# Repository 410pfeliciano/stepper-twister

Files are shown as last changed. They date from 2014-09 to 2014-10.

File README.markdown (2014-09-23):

=================================
An open-source, very fast tetrode twister for Arduino
=================================

This code requires the [Arduino](http://www.arduino.cc) development environment and an [Arduino board](http://www.sparkfun.com/products/11021>). 

The code has been updated to be compatible with the Arduino IDE version 1.0 and higher. To make it compatible with earlier versions of the IDE, simply include "WProgram.h" instead of "Arduino.h" in the TwisterClasses.h file.

This repository contains circuit board files, a parts list, and an instruction manual.

=================================
Attribution
=================================
This work is basically a direct combination of two existing open-source projects:

1. "Tetrode Twister" by Josh Siegle, which is licensed under [GPLv3](http://www.gnu.org/licenses/gpl-3.0.txt)
    * [Josh on Github](https://github.com/jsiegle)
    * [Twister Project](https://github.com/open-ephys/twister)

2. "Easy Driver" by Brian Schmalz, which is  is licensed under [CC-BY-3.0](https://creativecommons.org/licenses/by/3.0/us/)
    * [Brian's site](http://www.schmalzhaus.com/)
    * [Easy Driver Project](http://www.schmalzhaus.com/EasyDriver/)

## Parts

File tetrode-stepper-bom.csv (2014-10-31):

Sparkfun Part No. | Quantity | Description | Notes
prt-00116 | 2 | Header, 40 pin
com-09939 | 2 | Rotary Pot, 10K
com-10002 | 2 | Knob
LCD-0070 | 1 | LCD Module
DEV-11286 | 1 | Leonardo
TOL-00298 | 1 | Wall wart
COM-07950 | 1 | Buzzer
COM-09190 | 1 | Momentary switch
COM-08605 | 1 | Tall momentary switch
com-09806 | 1 | Trimpot, 10K
ROB-1055 | 1 | Small stepper motor
Digikey | Quantity | Description | Notes
620-1140-1-ND | 1 | Microstepping driver
565-2558-1-ND | 1 | CAP 47UF 35V ELECT MZA SMD
445-1291-1-ND | 2 | Ceramic Cap, 0603, 680pF
445-1419-1-ND | 2 | Ceramic Cap, 0805, 1uF
P10.0KHCT-ND | 8 | Resistor, 0603, 10K
P11.0KHCT-ND | 1 | Resistor, 0603, 11K
P20.0KHCT-ND | 2 | Resistor, 0603, 20K
A109863CT-ND | 2 | Resistor, 1206, 0.75 Ohm
MURS120T3GOSCT-ND | 1 | DIODE ULTRA FAST 200V 2A SMB
McMaster-Carr | Quantity | Description | Notes
94500A222 | 1 | M3 bolt | 100/pack
90592A009 | 1 | M3 Nut | 100/pack
94150a340 | 1 | M5 nut | 25/pack
91292a193 | 1 | M5 bolt | 50/pacl
92871a063 | 4 | M5 Unthreaded spacer, 20mm
92871a040 | 4 | M5 Unthreaded spacer, 5mm
Pololu | Quantity | Description | Notes
1079 | 1 | 3-mm shaft hub | 2/pack
Ponoko | Quantity | Description | Notes
cad/clip-holder.stl | 1 | 3-d printed clip holder | Material = fine, durable plastic, design: http://www.ponoko.com/design-your-own/products/clip-holder-11927
cad/motor-arm.stl | 1 | 3-d printed stepper motor arm | Material = fine, durable plastic, design: http://www.ponoko.com/design-your-own/products/clip-holder-11927

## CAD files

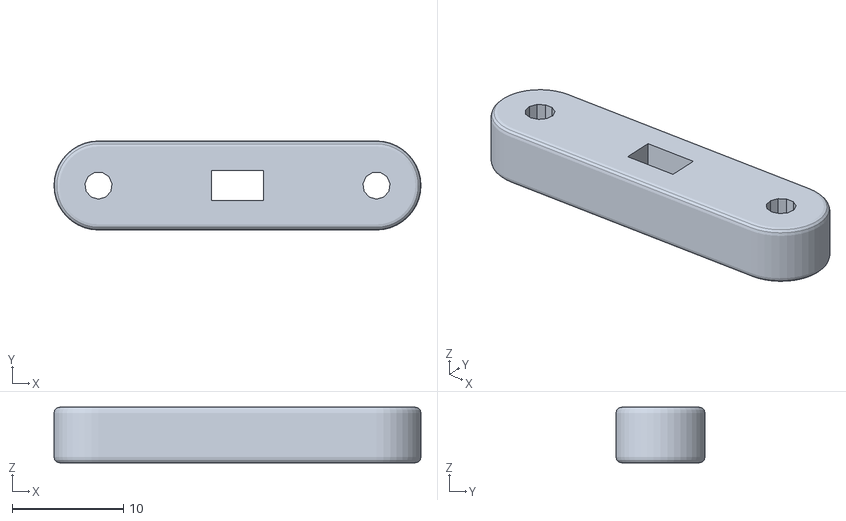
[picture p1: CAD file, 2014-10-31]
cad/clip-holder.stl
33.0 x 8.00 x 5.00

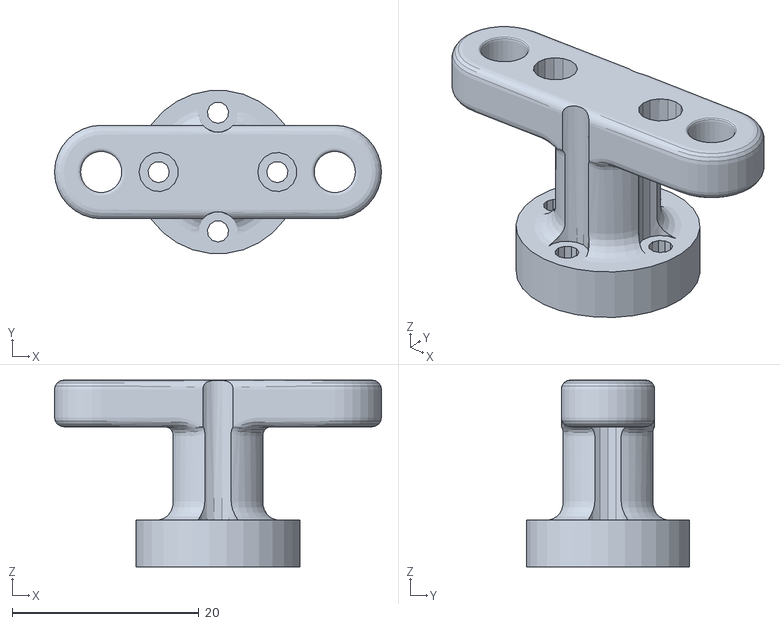
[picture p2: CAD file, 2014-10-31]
cad/motor-arm.stl
35.0 x 17.4 x 20.0

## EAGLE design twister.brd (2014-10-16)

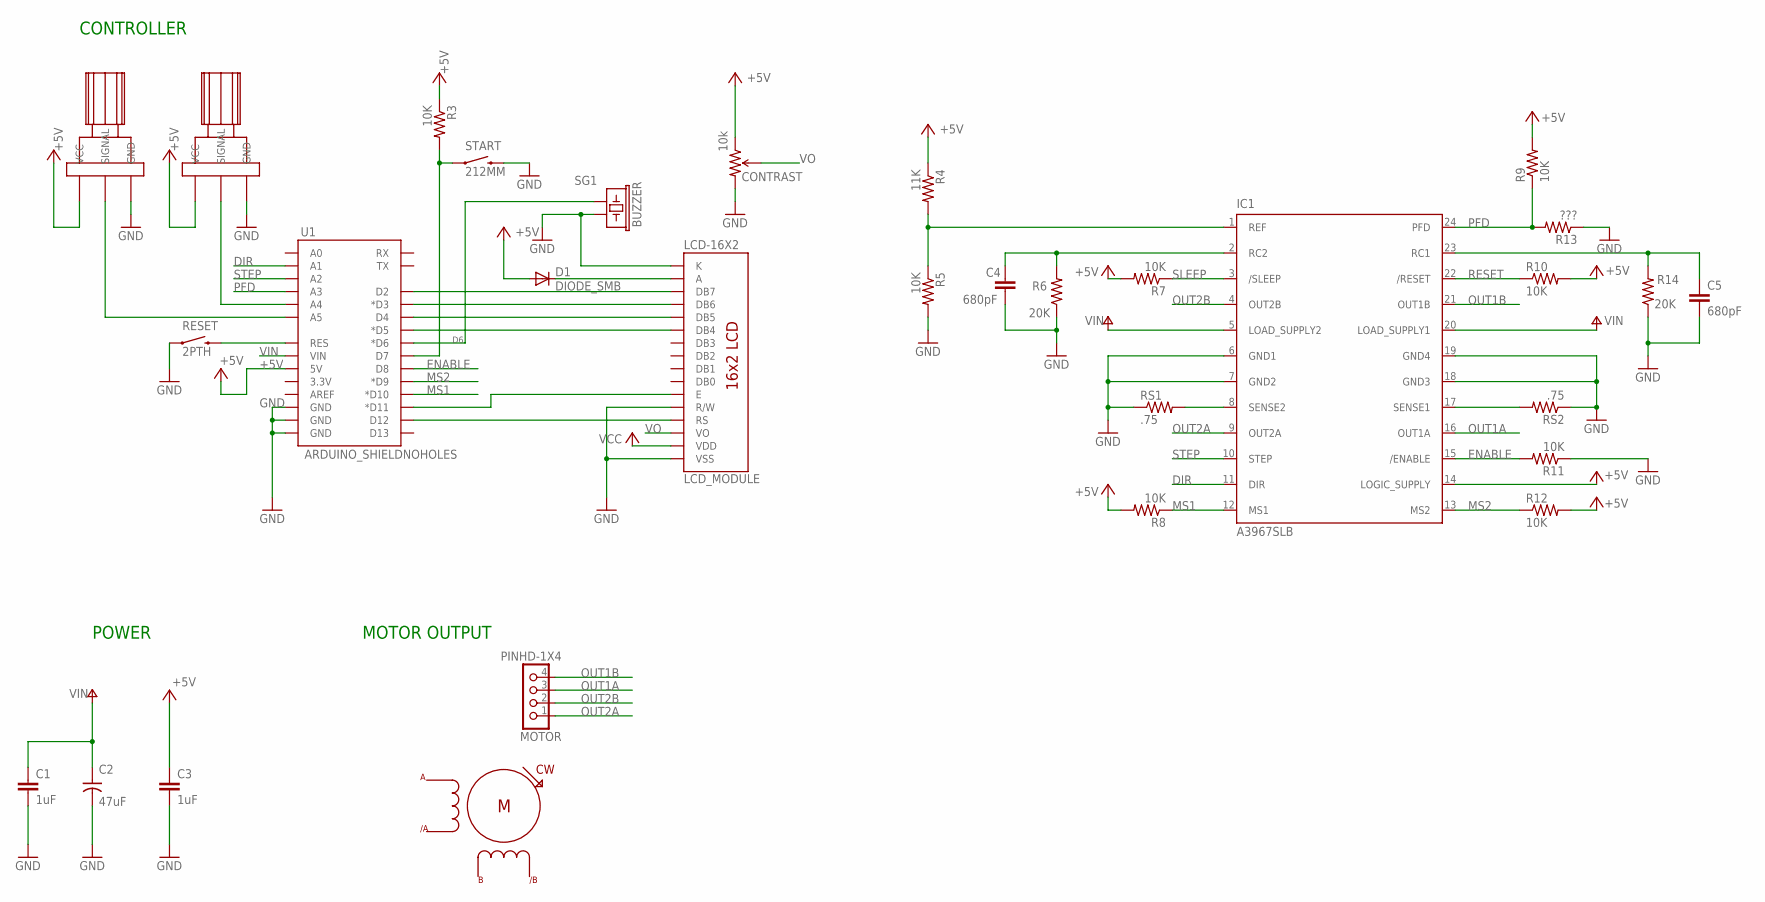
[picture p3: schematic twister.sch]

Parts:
BUZZER: SG1; BUZZER-12MM
C1, C3: 1uF; 0805
C2: 47uF; 153CLV-0807
C4, C5: 680pF; 0603
CONTRAST: 10k; 3362U-2
D1: DIODE_SMB; SMB
IC1: A3967SLB; SO24W
LCD_MODULE: LCD-16X2
MOTOR: PINHD-1X4; 1X04
R1, R2: R12-0; LARGE_POT
R3, R5, R7, R8, R9, R10, R11, R12: 10K; 0603
R4: 11K; 0603
R6, R14: 20K; 0603
R13: ???; 0603
RESET: 2PTH; TACTILE-PTH
RS1, RS2: .75; 1206
START: 212MM; TACTILE-PTH-12MM
STEPPER: ST-PM35; ST-PM35-15-11C
U1: ARDUINO_SHIELDNOHOLES; DUEMILANOVE_SHIELD_NOHOLES

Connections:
+5V: C3.1, CONTRAST.1 (CCW), D1.A, IC1.14 (LOGIC_SUPPLY), LCD_MODULE.2 (VDD), R1.LEFT (VCC), R2.LEFT (VCC), R3.1, R4.1, R7.2, R8.2, R9.2, R10.2, R12.2, U1.5V
A: D1.C, LCD_MODULE.15 (A)
D6: BUZZER.- (2), U1.D6 (*D6)
DIR: IC1.11 (DIR), U1.A1
ENABLE: IC1.15 (/ENABLE), R11.2, U1.D8
GND: BUZZER.+ (1), C1.2, C2.-, C3.2, C4.2, C5.2, CONTRAST.3 (CW), IC1.6 (GND1), IC1.7 (GND2), IC1.18 (GND3), IC1.19 (GND4), LCD_MODULE.1 (VSS), LCD_MODULE.5 (R/W), LCD_MODULE.16 (K), R1.RIGHT (GND), R2.RIGHT (GND), R5.2, R6.1, R11.1, R13.1, R14.1, RESET.1, RS1.1, RS2.1, START.3 (2), U1.GND@0 (GND), U1.GND@1 (GND), U1.GND@2 (GND)
MS1: IC1.12 (MS1), R8.1, U1.D10 (*D10)
MS2: IC1.13 (MS2), R12.1, U1.D9 (*D9)
unnamed: IC1.8 (SENSE2), RS1.2
unnamed: C4.1, IC1.2 (RC2), R6.2
unnamed: IC1.17 (SENSE1), RS2.2
unnamed: LCD_MODULE.4 (RS), U1.D12
unnamed: LCD_MODULE.6 (E), U1.D11 (*D11)
unnamed: LCD_MODULE.11 (DB4), U1.D5 (*D5)
unnamed: LCD_MODULE.12 (DB5), U1.D4
unnamed: LCD_MODULE.13 (DB6), U1.D3 (*D3)
unnamed: LCD_MODULE.14 (DB7), U1.D2
unnamed: R2.CENTER (SIGNAL), U1.A4
unnamed: R1.CENTER (SIGNAL), U1.A5
unnamed: R3.2, START.1, U1.D7
unnamed: C5.1, IC1.23 (RC1), R14.2
unnamed: IC1.1 (REF), R4.2, R5.1
OUT1A: IC1.16 (OUT1A), MOTOR.3
OUT1B: IC1.21 (OUT1B), MOTOR.4
OUT2A: IC1.9 (OUT2A), MOTOR.1
OUT2B: IC1.4 (OUT2B), MOTOR.2
PFD: IC1.24 (PFD), R9.1, R13.2, U1.A3
RESET: IC1.22 (/RESET), R10.1, RESET.3 (2), U1.RES
SLEEP: IC1.3 (/SLEEP), R7.1
STEP: IC1.10 (STEP), U1.A2
VIN: C1.1, C2.+, IC1.5 (LOAD_SUPPLY2), IC1.20 (LOAD_SUPPLY1), U1.VIN
VO: CONTRAST.2 (WIPER), LCD_MODULE.3 (VO)

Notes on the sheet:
POWER
CONTROLLER
MOTOR OUTPUT

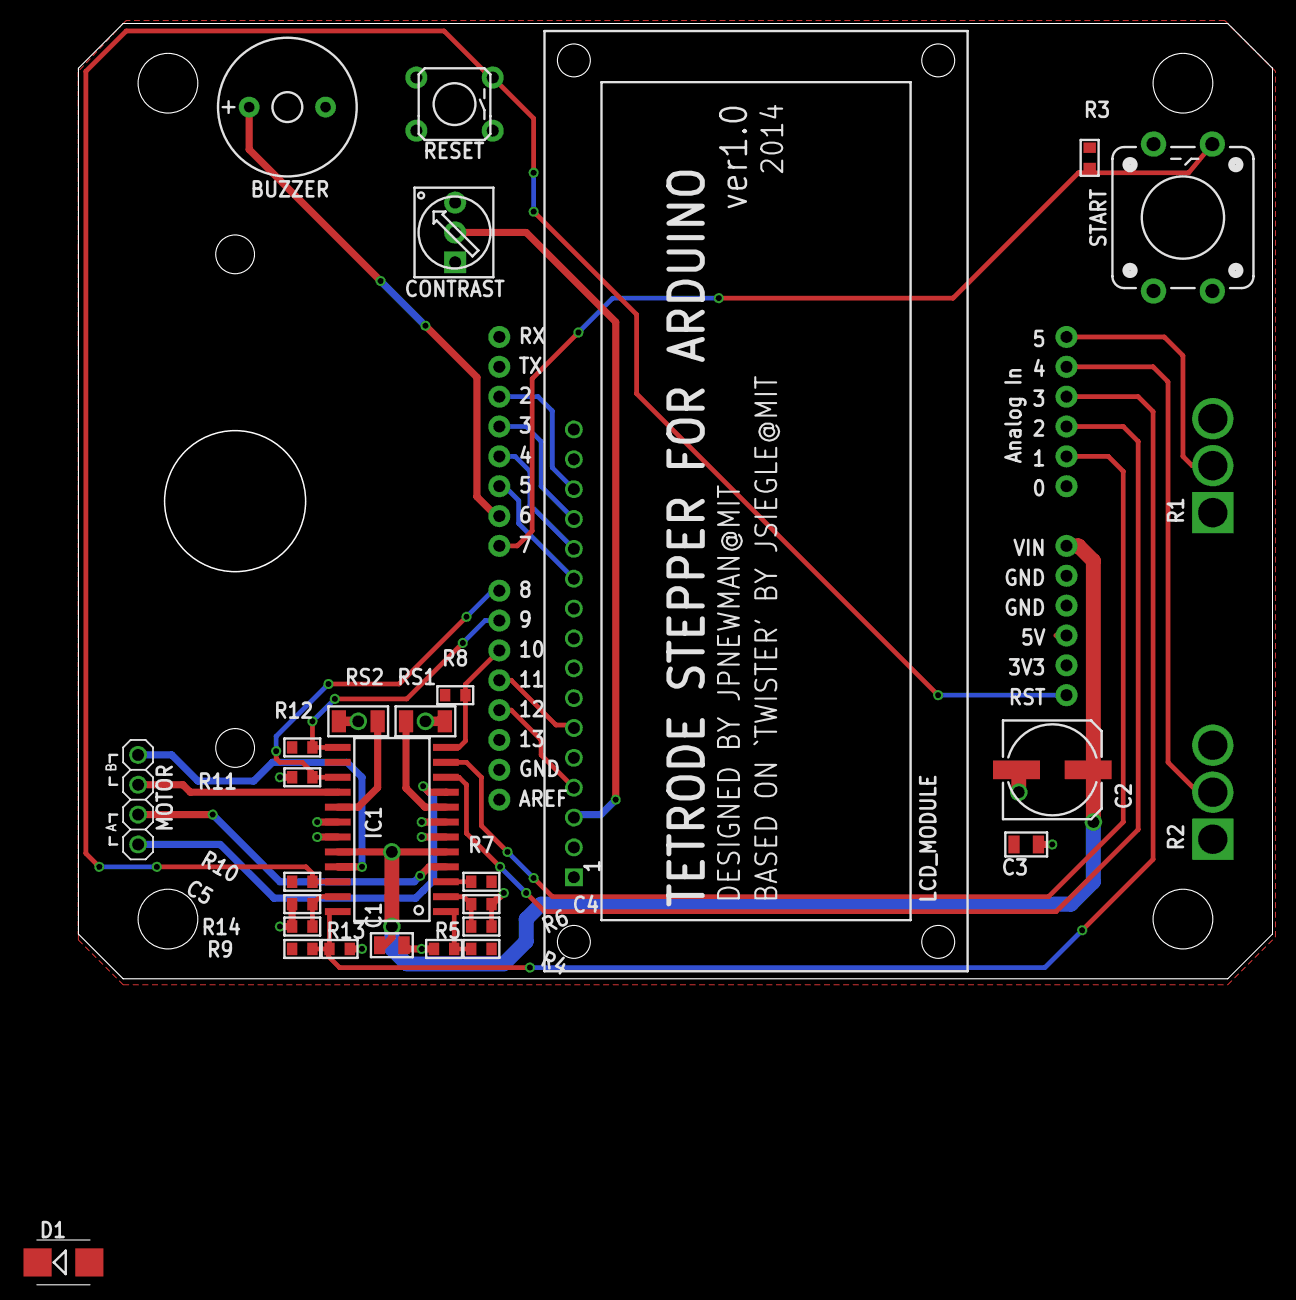
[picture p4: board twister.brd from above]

Board: 2 copper layers, 101.6 x 81.3 mm, 31 parts (1 on the bottom side), 32 nets.

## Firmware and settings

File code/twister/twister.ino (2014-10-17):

//    Tetrode Twister Control Software
//    Copyright (C) 2011 Josh Siegle
//
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

// -------------------------------------------------------------------- //
/*    DEBUG MODE?
 
 If debugMode is set to 'true', photocell values and thresholds
 will be printed to the serial port. These can be visualized 
 using the accompanying Processing sketch, 'PhotocellVisualization.pde'
 
 If printState is set to 'true', total turns, forward turns, reverse turns,
 button state, and counter state will be printed to the serial port.
 
 */

boolean debugMode = false;

/*   SAVE STATE?
 
 If saveState is set to true, the Arduino will save its current status
 after each turn. The state can then be restored if the Arduino loses
 power or is reset while turning.
 
 */

boolean saveState = false;

// -------------------------------------------------------------------- //

// BEGIN ACTUAL CODE:

// Includes
#include <AccelStepper.h>
#include <LiquidCrystal.h>
#include <EEPROM.h>
#include "TwisterClasses.h"

// Initialize servo and LCD
LiquidCrystal lcd(LCDRS, LCDEN, LCDD4, LCDD5, LCDD6, LCDD7);

// Initialize Stepper object
// 1 = Use chopper driver
// A2 = step command
// A1 = direction command 
AccelStepper stepper(STEPMODE, STEP, DIR);
StepperControl stepperCont;

// Buzzer and dials
Buzzer buzzer(BUZZER); // Board 1.1 = 6, Board 1.0 = 7
Inputs inputs(STARTSTOP,KNOB1,KNOB2); // Board 1.1 = 7, Board 1.0 = 6

// State tracker
StateTracker twister;

// EEPROM variables
int remainingTurns;
int turnDirection;

void setup()
{

	// Set default stepper driver options
	stepperCont.setParameters();
	stepper.setMaxSpeed(stepperCont.getMaxSPS());
	stepper.setAcceleration(stepperCont.getMaxSPS());

	// start up servo and LCD screen
	lcd.begin(16,2);

	if (debugMode) {
		Serial.begin(9600);
	}

	startupScreen(0,1);  // Display the welcome message
}

void loop()
{
	// Main information update function
	inputs.check(twister.isTurning);

	// If we are actually turning the motor
	if (twister.isTurning) { 

		// Are we there yet?
		if (stepper.distanceToGo() == 0) {
			if (twister.isTurningFWD && !twister.finished) {

				// Set steppar target distance
				stepperCont.setDistance(inputs.fwdTurns);
				stepper.moveTo(stepperCont.targetPos);
				twister.isTurningFWD = false;
				twister.finished = false;
			}
			else if (!twister.isTurningFWD && !twister.finished) {

				// Indicate turn around
				buzzer.low();
				delay(500);

				stepperCont.setDistance(-inputs.revTurns);
				stepper.move(stepperCont.targetPos);
				twister.isTurningFWD = true;
				twister.finished = true;
			}
			else {

				// Indicate that we are finished
				buzzer.low();
				delay(100);
				buzzer.high();
				delay(100);
				buzzer.low();
				delay(100);
				buzzer.high();
				delay(100);

				// Reset the state machine
				allDone();
				twister.isTurningFWD = true;
				twister.isTurning = false;
				twister.finished = false;
				twister.isUpdated = true;
				stepper.setCurrentPosition(0);
				delay(2000);
			}
		}

		// Take a step
		stepper.run();

	}
	else {

		stepperCont.getCompletedTurns(stepper.currentPosition());

		if (twister.totalTurns != stepperCont.completedTurns) {
			twister.totalTurns = stepperCont.completedTurns;
			twister.isUpdated = true; // necessary to update LCD
		}

		// Update the number of completed turns
		showTurns(); // update LCD screen
	}

	if (inputs.buttonState == LOW) { // check for button press
		twister.respondToButton();
                twister.isUpdated = true;
		if (twister.isTurning) {
			showTurningDialog();

                        // Re call moveTo and reset the position to restart Accel process
                        long toGo = stepper.distanceToGo();
                        stepper.setCurrentPosition(0);
                        stepper.moveTo(toGo);
                }
		
		delay(250);
	}
}

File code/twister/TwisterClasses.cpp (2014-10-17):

//    Tetrode Twister Control Software
//    Copyright (C) 2011 Josh Siegle
//
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

#include "TwisterClasses.h"

// Buzzer methods:

Buzzer::Buzzer(int pin)
{
  pinMode(pin, OUTPUT);
  _pin = pin;
}

void Buzzer::high()
{
  tone(_pin,2000,200);
}

void Buzzer::low()
{
  tone(_pin,1000,200);
  
}

// Inputs methods:

Inputs::Inputs(int pin1, int pin2, int pin3)
{
	pinMode(pin1, INPUT);
	_buttonPin = pin1;
	_knobPin1 = pin2;
	_knobPin2 = pin3;
	buttonState = 0;
	fwdTurns = 0;
	revTurns = 0;
	isUpdated = true;
}

void Inputs::check(boolean isTurning)
{
	buttonState = digitalRead(_buttonPin); // read button state

	if (!isTurning) { // allow changes only if twister isn't turning

		// Board ver 1.1:
		int knob1 = analogRead(_knobPin1) / 4 * 100 / 255;
		int knob2 = analogRead(_knobPin2) / 4 * 100 / 255;

		// constrain values to be between 0 and 100
		knob1 = min(knob1,100); 
		knob1 = max(knob1,0);
		knob2 = min(knob2,100); 
		knob2 = max(knob2,0);

		if (knob1 != fwdTurns || knob2 != revTurns) { // check to see if values have been updated
			isUpdated = true;
		}

		Serial.print("knob 1: ");
		Serial.print(knob1);
		Serial.print("\n");
		fwdTurns = knob1;
		revTurns = knob2;

	}
}


// StateTracker methods:

StateTracker::StateTracker()
{
	isTurning = false;
	isTurningFWD = true;
	isUpdated = false;
	totalTurns = 0;
	finished = false;
}

void StateTracker::respondToButton()
{
	isTurning = !(isTurning);
}

// StepperControl Methods:

StepperControl::StepperControl()
{
	maxRPS = 20;
	stepen = true;
	ms1 = false;
	ms2 = true;
	pfd = true;
}

void StepperControl::setParameters(void)
{	
	// Set pin modes
	pinMode(STEPEN, OUTPUT);
	pinMode(MS1, OUTPUT);
	pinMode(MS2, OUTPUT);
	pinMode(PFD, OUTPUT);

	// Set microstep resolution
	if (!ms1 & !ms2)
		_nUSteps = 1;
	else if (ms1 & !ms2)
		_nUSteps = 2;
	else if (!ms1 & ms2)
		_nUSteps = 4;
	else
		_nUSteps = 8;

	// Set the max speed (steps/second)
	_maxSPS = (float)(maxRPS*SPR*_nUSteps);

	// Write to the parameter pins
	digitalWrite(STEPEN,!stepen);
	digitalWrite(MS1, ms1);
	digitalWrite(MS2, ms2); 
	digitalWrite(PFD, pfd); 
}

void StepperControl::setDirection(bool forward)
{
	stepDir = forward;
}

void StepperControl::setDistance(int turns)
{
	targetPos = (long)(turns*_nUSteps*SPR);
}

void StepperControl::getCompletedTurns(long currentCompletedSteps)
{
	completedTurns = ceil(currentCompletedSteps/(long)(_nUSteps*SPR));
}

float StepperControl::getMaxSPS(void)
{
   return _maxSPS; 
}

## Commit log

2014-09-23 Added the easy driver board an simply imported into the existing twister design.
    [EasyDriver_v44.brd, EasyDriver_v44.sch, EasyDriver_v44_BOM.xls]
2014-09-25 Got rid of unnessary jumpers on stepper driver circuit and instead sent to open io pins on arduino.
    [twister.brd, twister.sch]
2014-09-25 Added stepper motor.
    [twister.brd, twister.sch]
2014-09-27 Everything should be set for final layout.
    [twister.brd, twister.sch]
2014-09-28 Halfway through layout.
    [twister.brd, twister.sch]
2014-09-29 Just about finished. Need to clean up aux materials so they actually match the pcb.
    [twister.brd, twister.sch]
2014-10-01 Finished rev 1.0 and sent to fab.
    [EasyDriver_v44.brd, EasyDriver_v44.sch, EasyDriver_v44_BOM.xls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]
2014-10-16 Put together first PCB, started documenting improvements.
    [twister.brd, twister.sch]
2014-10-16 cam and bom updates.
    [tetrode-stepper-bom.csv]
2014-10-17 System is working pretty well. I need a better way to couple the motor shaft to the arm piece.
2014-10-31 Designed a new tetrode holder capable of handling the high speeds of the twister.
    [clip-holder.stl, motor-arm.stl, tetrode-holder.cfg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]
2014-10-31 Finished the new tetrode holder. Ordered parts.
    [clip-holder.stl, motor-arm.stl, tetrode-holder.cfg]
2014-10-31 Update BOM.
    [tetrode-stepper-bom.csv]

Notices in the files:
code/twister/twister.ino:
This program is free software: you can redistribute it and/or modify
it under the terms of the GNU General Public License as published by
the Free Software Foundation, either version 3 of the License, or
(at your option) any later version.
